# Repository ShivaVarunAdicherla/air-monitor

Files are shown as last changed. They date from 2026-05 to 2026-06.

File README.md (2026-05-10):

# Air Monitor
## Status
- PCB Design - Completed
- Components - Arrived
- Firmware - BLE advertisement tested
- Enclosure - In progress - [Here](https://cad.onshape.com/documents/7cc096864f16c057a6e9d4d9/w/91c0470fa62f2376e8363204/e/8dff4a441c052faf6f8fa123)
- Order Status - Placed and Inprogress/Pre-Engineering

# $\mu$Air
$\mu$Air is a compact air monitoring device, capable of measuring concentrations of multiple essential local atmospheric parameters like: 
- PM2.5 - Particulate Matter
- Nitrogen Oxides ($NO_x$) 
- Carbon Dioxide ($CO_2$)
- Volatile Organic Compounds (VOCs)
- Temperature and Humidity

Each of these is measured using the following:
- BMV080 - Particulate Matter:
  - Compact - 4.4mm x 3.0mm x 4.4mm
  - $1\frac{\mu g}{m^3}$ PM mass concentration resolution
  - Fanless, uses lasers 
- SGP41 - VOCs and $NO_x$ 
- SCD40 - $CO_2$, temperature and humidity

While each of these parameters is measured and can be monitored/inspected individually, an overall quantitative measure of the ambient atmosphere, the AQI (Air Quality Index), is also calculated using these parameters. 

## User Interaction:
AQI, as well as each of the parameters, individually, can be accessed by the user in two ways:
1. 0.96'' OLED Display on device - Push button to wake
2. HomeAssistant App/Server

## Implementation


## Schematic


### Explanation
1. Power
   - Primary Source: 1000mAh Li-Po Battery, or direct power from USB, when connected - Bypass charging handled using a PMOS and a schottky diode, as seen in the schematic.
   - Regulated Power Supply: Buck converter (whose input comes from the output of the bypass charging module - PMOS + Schottky) steps $VIN$ down to $3.3V (V_{DD})$.
   - All other modules, including ESP32-C3 and all the sensors use 3.3V $V_{DD}$ as their power supply.
   - Battery Charging: Handled by DW01 (battery protection IC, inbuilt into the 1000mAh battery), and TC4056, battery charging IC (CC-CV).
2. Sensors
   - BMV080: Measuring PM10, PM2.5 and PM1.0 - Comes in a flex PCB package, with a corresponding female connector placed on the PCB.
   - SCD40: Measuring $CO_2$
   - SGP41: Measuring VOCs and $NO_x$
   - Communication via common I2C bus (except for the BMV080, which has a separate I2C bus) to the ESP32-C3
   - Enclosure designed with suitable openings to allow normal/optimal functioning of all the sensors, as mentioned in their respective application manuals.
3. MCU: ESP32-C3
   - Controls the common I2C bus to receive measurments from the sensors.
   - Handles BLE advertising at regular intervals.
   - Goes into sleep when not broadcasting, saving battery life.
   - Handles the display via the common I2C bus along with a wake button to view parameters on the display.

## PCB Layout




## Firmware Status:
### Framework: ESP-IDF, MicroController: ESP32-C3
For Integration with **Home Assistant** without any other extra configuration for BLE based data broadcast devices, there's an open standard called **BTHome**.
The Second version of the standard has been released quite recently, and the official **BTHOME** component from Espressif doesn't seem to work because it has probably been **depreciated**.

Right now, the code initializes Bluetooth's BLE Stack by Apache Foundation (NimBLE), and starts advertising packets with an interval of 450ms (We've decided on
this rate to save power, while maintaining the balance of packet reception). Right now, since actually don't have the sensor data, we're just generating a random
number/data then building the advertisement packet and sending $\approx 16$ packets in a task loop.

**Note:** We're are building our own implementation of *BTHOME* which sends the sensor data, in the service region of the advertisement packet.

Since ESP-IDF has a native port of FreeRTOS, we plan to take advantage of it's powerful scheduling capabilities to make it easier to organise and build modules
which perform certain tasks. The flowchart will look something like this.



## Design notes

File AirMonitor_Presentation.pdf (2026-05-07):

## Electronic System Design Project Lab

## Air Monitor

Shiva Varun Adicherla EE24BTECH11201 | Anoop K | EE24BTECH11203
Sai Vedhamsh Kema EE24BTECH11211 Shubhang Kulkarni EE24BTECH11222

## 1 Features:

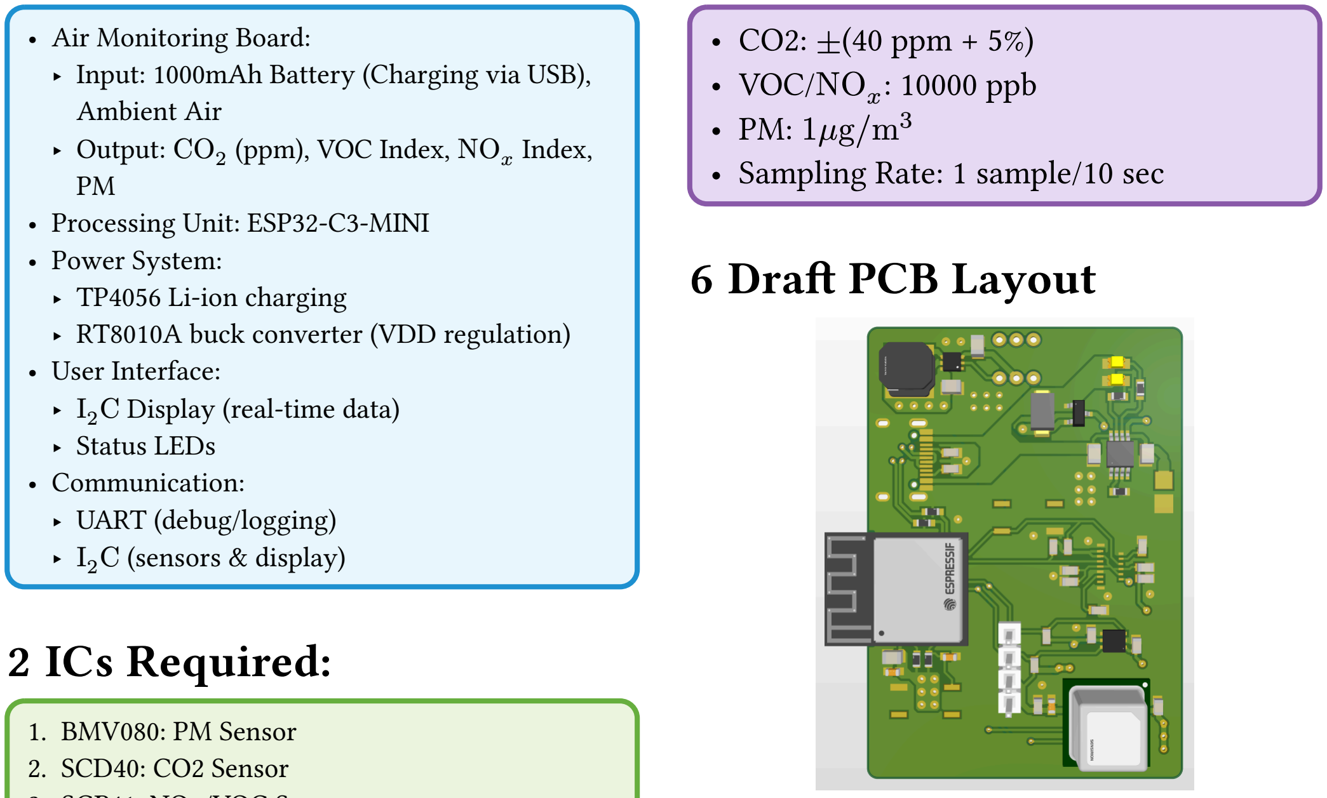
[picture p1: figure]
• Air Monitoring Board:; Ambient Air ‣ Output: CO2; (ppm), VOC Index, NOx; Index,; PM • Processing Unit: ESP32-C3-MINI • Power System: ‣ TP4056 Li-ion charging; • User Interface: ‣ I2C Display (real-time data) ‣ Status LEDs • Communication: ‣ UART (debug/logging) ‣ I2C (sensors & display); 2 ICs Required:; 1. BMV080: PM Sensor 2. SCD40: CO2 Sensor; • CO2: ±(40 ppm + 5%) • VOC/NOx; : 10000 ppb • PM: 1μg/m³; • Sampling Rate: 1 sample/10 sec; 6 Draft PCB Layout

- Input: 1000mAh Battery (Charging via USB),
- RT8010A buck converter (VDD regulation)
3. SGP41: NOx/VOC Sensor
4. TC4056: Battery charger IC
5. ESP32-C3-MINI: MCU
6. RT8010/A: DC-DC Converter

## 3 Cost

### - Components (Active+Passive): 6900 INR

## 4 Block Diagram

## 5 Measurement Specifications

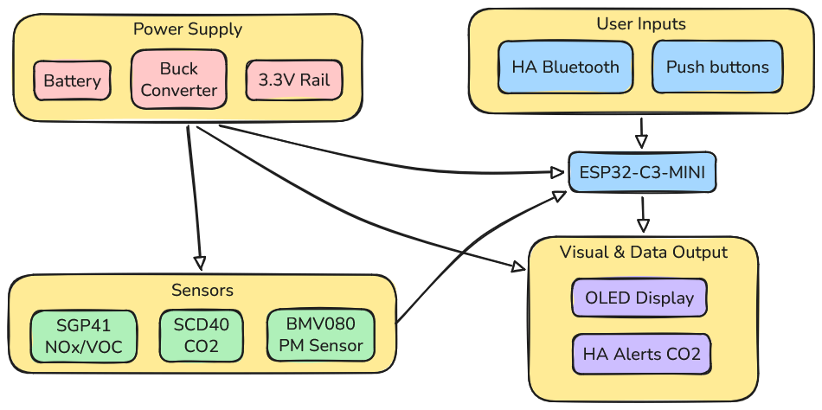
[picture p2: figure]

# EE2504 - Project Idea Local Climate Monitor

19-03-2026

# Our Idea - Smart Air Quality Monitor

# Problem :

# 1. Most indoor workplaces are not monitored for potentially harmful

environments.

# 2. If monitored also, not coupled with IoT for remote access / control

of other IoT devices.

# Our Idea - Smart Air Quality Monitor

# Solution:

## 1. Constantly monitor local environmental

parameters (air quality, CO2 levels,

## temperature, humidity) 2. Make remote access available (along with alerts in certain cases of abnormal changes in parameters) 3. Extension - use this data to control other IoT devices (example: controlling an air purifier fan based on AQI, controlling a fan based on temp/humidity )

# Block diagram

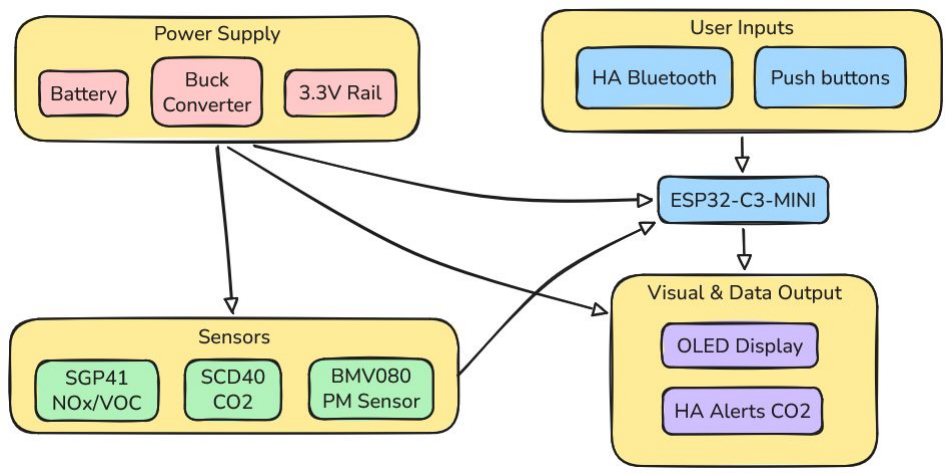
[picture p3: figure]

# Targets

# - Realtime parameters monitoring using input of multiple sensors - IoT integration with Home Assistant

## - Alerts (abnormal change in parameters) - Realtime Info

# Sensors

# - BMV080 sensor for measuring particulate matter - SCD40 for CO2 as well as measuring temperature and humidity - SGP41

- Gas sensor - NOx , VOC etc..

# Components and cost

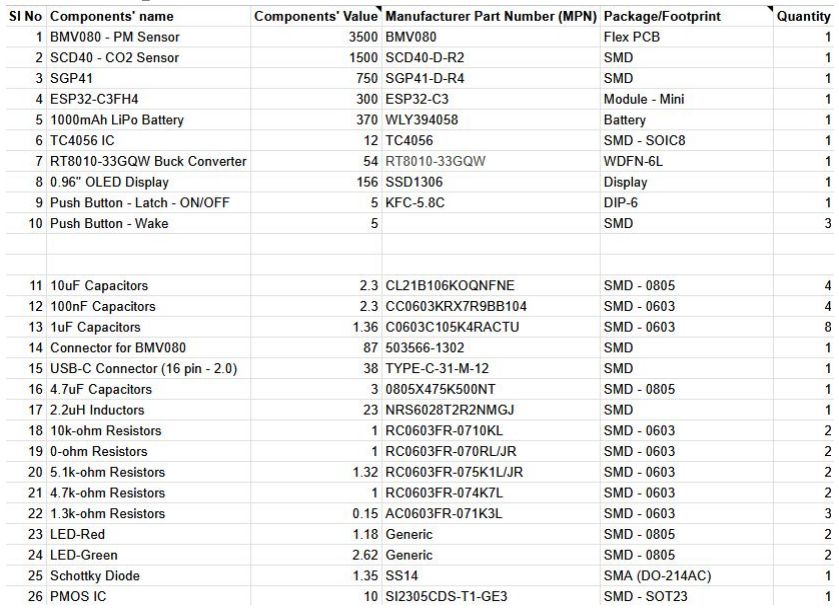
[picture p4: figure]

# Thank you

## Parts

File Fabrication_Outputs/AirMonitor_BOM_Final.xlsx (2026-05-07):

Name | Description | Manufacturer 1 | Manufacturer Part Number 1 | Supplier 1 | Supplier Part Number 1 | DNP | Total Quantity | Designators
C0603C105K4RACTU | 16V 1uF X7R ±10% 0603 Multilayer Ceramic Capacitors MLCC - SMD/SMT ROHS | Yageo Group | C0603C105K4RACTU |  |  |  | 8 | C1, C2, C3, C4, C8, C14, C15, C17
CL21B106KOQNFNE | Multilayer Ceramic Capacitor, 10 uF, 10 V, ± 10%, X7R, 0805 [2012 Metric] | Murata | CL21B106KOQNFNE |  |  |  | 4 | C5, C6, C10, C12
CC0603KRX7R9BB104 | Multilayer Ceramic Capacitor, CC Series, 0.1 - F, - 10%, X7R, 50 V, 0603 [1608 Metric] | Yageo Group | CC0603KRX7R9BB104 |  |  |  | 3 | C7, C9, C11
0805X475K500NT | 0805X475K500NT-FH -50V 4.7uF X5R±10% 0805 Multilayer Ceramic Capacitors MLCC – SMD/SMT ROHS | FH (Guangdong Fenghua Advanced Tech) | 0805X475K500NT |  |  |  | 1 | C13
LEDRED | LED RED CLEAR 0805 SMD | Generic_RED | Generic_RED | Robu.in | 827887 |  | 1 | D1
LEDGREEN | LED GREEN CLEAR 0805 SMD | Generic_GREEN | Generic_GREEN | Robu.in | 827885 |  | 1 | D2
SS14 | SS14-Slkor-40V 550mV@1A 1A SMA(DO-214AC) Schottky Diodes ROHS | Slkor | SS14 | Robu.in | R193202 |  | 1 | D3
5035661302 | Easy-On FPC Connector, 0.30mm Pitch, Right-Angle, Bottom Contact, 0.95mm Height, 13 Circuits, Gold over Nickel Plating | Molex Connector Corporation | 5035661302 | Mouser | 538-503566-1302 |  | 1 | J1
TYPE-C-31-M-12 | TYPE-C-31-M-12-Hroparts-5A 1 16P Female Type-C SMD USB Connectors ROHS | HRO Electronics | TYPE-C-31-M-12 | Robu.in | R243053 |  | 1 | J2
NRS6028T2R2NMGJ | Inductor Power Shielded Wirewound 2.2uH 30% 100KHz Ferrite 3.7A 0.026Ohm DCR 2424 T/R | TAIYO YUDEN | NRS6028T2R2NMGJ | Digikey | 587-2939 |  | 1 | L1
ESP32-C3-MINI-1-H4 | -96dBm 20.5dBm PCBAntenna 2.4GHz SMD, 13.2x16.6mm WiFi Modules ROHS | Espressif Systems | ESP32-C3-MINI-1-H4 | Digikey | 5407-ESP32-C3-MINI-1-H4 |  | 1 | MD1
Berg Pins | 0.025" SQ Post Header, Through-hole, Vertical, -55 to 125 degC, 2.54 mm Pitch, 4-Pin, Male, RoHS |  | DNP |  |  | YES | 1 | P1
AC0603FR-071K3L | RES 1.3KΩ 1.00% 0.1W 0603 | Yageo Group | AC0603FR-071K3L | Robu.in | R137937 |  | 3 | R1, R2, R5
RC0603FR-075K1L | Res Thick Film 0603 5.1K Ohm 1% 0.1W(1/10W) ±100ppm/C Pad SMD T/R | Yageo Group | RC0603FR-075K1L | Robu.in | R135867 |  | 4 | R3, R4, R14, R15
RC0603FR-0710KL | 100mW Thick Film Resistors ±100ppm/℃ ±1% 10kΩ 0603 Chip Resistor - Surface Mount ROHS | Yageo Group | RC0603FR-0710KL | Robu.in | R242876 |  | 2 | R6, R7
GPR06034K7 | SMD Chip Resistor, 4.7 kohm, ± 1%, 100 mW, 0603 [1608 Metric], Thick Film, General Purpose | PCBPower | GPR06034K7 | PCBPower |  |  | 4 | R8, R9, R10, R11
RC0603FR-070RL | Zero Ohm Resistor, Jumper, 0603 [1608 Metric], Thick Film, 100 mW, 1 A, Surface Mount | Yageo Group | RC0603FR-070RL | Robu.in | 1797992 |  | 2 | R12, R13
TK-052 | Tact Switch-TK-052-4 Pin 4×4 | Generic | TK-052 | Robu.in | 1883750 |  | 3 | SW1, SW2, SW3
KFC-5.8C | Self Lock Switch-KFC-KFC-5.8C | Generic | KFC-5.8C | Robu.in | 1883578 |  | 1 | SW4
TC4056 | TC4056-Fumen Electronics Co. Ltd.-1A Standalone Linear Li-Ion Battery Charger IC 8-SOIC | Fuman | TC4056 | Robu.in | R162796 |  | 1 | U1
SCD40-D-R2 | Air Quality Sensor CO2 Sensor 2.5V/3.3V/5V 20-Pin SMD EP T/R | Sensirion | SCD40-D-R2 | Robu.in | R155005 |  | 1 | U2
SI2305CDS-T1-GE3 | P-CHANNEL 8-V (D-S) MOSFET | Vishay | SI2305CDS-T1-GE3 | Robu.in | R231218 |  | 1 | U3
RT8010-33GQW | Switching Regulator, Voltage-mode, 1A, 1800kHz Switching Freq-Max, PDSO6 | Richtek | RT8010-33GQW | DigiKey | 1028-RT8010-33GQW |  | 1 | U4
SGP41-D-R4 | NOx and VOC Sensor with a Secondary Humidity and Temperature Output | Sensirion | SGP41-D-R4 | DigiKey | 1649-SGP41-D-R4 |  | 1 | U5

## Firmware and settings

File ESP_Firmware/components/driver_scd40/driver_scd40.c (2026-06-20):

#include "include/driver_scd40.h"
#include "driver/i2c_types.h"
#include "esp_compiler.h"
#include "esp_err.h"
#include "esp_log.h"
#include "esp_log_buffer.h"
#include "esp_log_level.h"
#include "freertos/idf_additions.h"
#include "freertos/projdefs.h"
#include "hal/i2c_types.h"
#include <driver/i2c_master.h>
#include <stdint.h>

// Logging toggle
#define LOG
#ifdef LOG
#define OLOG(x) ESP_LOGI("SCD40 Driver", x)
#else
#define OLOG(x) x
#endif

// Command List, obtained from pg.no 8 of SCD4X Datasheet. (Big endian)
#define SCD40_START_PERIODIC_MEASUREMENT (uint16_t *)"\x21\xb1"
#define SCD40_START_LOW_POWER_PERIODIC_MEASUREMENT (uint16_t *)"\x21\xac"
#define SCD40_STOP_PERIODIC_MEASUREMENT (uint16_t *)"\x3f\x86"
#define SCD40_GET_DATA_READY_STATUS (uint16_t *)"\xe4\xb8"
#define SCD40_READ_MEASUREMENT (uint16_t *)"\xec\x05"
#define SCD40_REINIT (uint16_t *)"\x36\x46"

esp_err_t scd40_init(i2c_master_bus_handle_t bus_handle, uint32_t speed,
                     scd40 *device) {
  i2c_device_config_t config = {.device_address = 0x62,
                                .dev_addr_length = I2C_ADDR_BIT_LEN_7,
                                .scl_speed_hz = speed,
                                .flags.disable_ack_check = false,
                                .scl_wait_us = 5000};

  return i2c_master_bus_add_device(bus_handle, &config, &device->dev_handle);
}

uint8_t scd40_crc(const uint8_t *data, uint8_t count) {
  // We init CRC checks with 0xFF (Pg: 23 of SCD4X Datasheet)
  uint8_t crc = 0xFF;
  const uint8_t CRC_POLY = 0x31;

  for (uint8_t current_byte = 0; current_byte < count; current_byte++) {
    crc ^= data[current_byte];
    for (uint8_t bit = 8; bit > 0; bit--) {
      if (crc & 0x80) // Check MSB
        crc = (crc << 1) ^ CRC_POLY;
      else
        crc = (crc << 1);
    }
  }
  return crc;
}

esp_err_t scd40_send_command(const uint16_t *command, scd40 *device) {
  return i2c_master_transmit(device->dev_handle, (uint8_t *)command, 2, 15);
}

esp_err_t scd40_read(const uint16_t *command, scd40 *device, uint8_t *buffer,
                     uint8_t length, uint8_t delay_in_ms) {
  esp_err_t error =
      i2c_master_transmit(device->dev_handle, (uint8_t *)command, 2, 15);
  if (unlikely(error != ESP_OK)) {
    OLOG("Failed a I2C Transmit");
    return error;
  }

  vTaskDelay(pdMS_TO_TICKS(delay_in_ms));

  error = i2c_master_receive(device->dev_handle, buffer, length, 15);
  if (unlikely(error != ESP_OK)) {
    OLOG("Failed a I2C Receive");
    return error;
  }
  esp_log_buffer_hex_internal("SCD40 Driver", buffer, length, ESP_LOG_INFO);

  return error;
}

esp_err_t scd40_start_periodic_measurement(scd40 *device) {
  OLOG("Starting Periodic Measurement");
  return scd40_send_command(SCD40_START_PERIODIC_MEASUREMENT, device);
}

esp_err_t scd40_start_low_power_periodic_measurement(scd40 *device) {
  OLOG("Starting Low Power Periodic Measurement");
  return scd40_send_command(SCD40_START_LOW_POWER_PERIODIC_MEASUREMENT, device);
}

esp_err_t scd40_stop_periodic_measurement(scd40 *device) {
  OLOG("Stopping Periodic Measurement");
  return scd40_send_command(SCD40_STOP_PERIODIC_MEASUREMENT, device);
}

esp_err_t scd40_read_measurement(scd40 *device, int *temp_c_deg,
                                 int *humidity_rh_percent, uint16_t *co2_ppm) {

  // TODO: Add Define Options to enable checking CRC. (We aren't checking now)

  uint8_t buf[9];
  esp_err_t error = scd40_read(SCD40_READ_MEASUREMENT, device, buf, 9, 2);
  if (unlikely(error != ESP_OK)) {
    OLOG("Failed Reading Measurement");
    *temp_c_deg = 0;
    *humidity_rh_percent = 0;
    *co2_ppm = 0;
    return error;
  }

  // Tick Conversion - SCD4X Datasheet pg.no 9
  *temp_c_deg = ((((int)buf[3] << 8) | buf[4]) * 175) / ((1 << 16) - 1) - 45;
  *humidity_rh_percent =
      ((((int)buf[6] << 8) | buf[7]) * 100) / ((1 << 16) - 1);
  *co2_ppm = ((uint16_t)buf[0] << 8) | buf[1];
  OLOG("Read measurements");
  return error;
}

uint8_t scd40_get_data_ready_status(scd40 *device) {
  uint8_t buf[3];
  scd40_read(SCD40_GET_DATA_READY_STATUS, device, buf, 3, 2);
  // OLOG("Polled for data ready flag");
  return (((uint16_t)buf[0] << 8) | buf[1]) &
         0x7FFF; // SCD4X Datasheet pg.no 16
}

esp_err_t scd40_reinit(scd40 *device) {
  OLOG("Restarting SCD40");
  return scd40_send_command(SCD40_REINIT, device);
}

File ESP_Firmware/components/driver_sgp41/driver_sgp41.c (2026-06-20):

#include "driver_sgp41.h"
#include "driver/i2c_master.h"
#include "driver/i2c_types.h"
#include "esp_err.h"
#include "esp_log.h"
#include "esp_log_buffer.h"
#include "esp_log_level.h"
#include "freertos/idf_additions.h"
#include "freertos/projdefs.h"
#include "hal/i2c_types.h"
#include <esp_compiler.h>
#include <stdint.h>

// Logging toggle
#define LOG
#ifdef LOG
#define OLOG(x) ESP_LOGI("SGP41 Driver", x)
#define OLOGF(x, y) ESP_LOGI("SGP41 Driver", x, y)
#define OLOGF2(x, y, z) ESP_LOGI("SGP41 Driver", x, y, z)
#else
#define OLOG(x) x
#define OLOGF(x, y) x
#define OLOGF2(x, y, z) x
#endif

esp_err_t sgp41_init(i2c_master_bus_handle_t bus_handle, uint32_t speed,
                     sgp41 *device) {
  i2c_device_config_t config = {
      .device_address = 0x59,
      .dev_addr_length = I2C_ADDR_BIT_LEN_7,
      .scl_speed_hz = speed,
      .scl_wait_us = 20000,
      .flags.disable_ack_check = true,
  };

  OLOG("SGP41 Sensor Init");
  return i2c_master_bus_add_device(bus_handle, &config, &device->dev_handle);
}

uint8_t sgp41_crc(const uint8_t *data, uint8_t count) {
  // We init CRC checks with 0xFF (Pg: 13 of SGP41 Datasheet)
  uint8_t crc = 0xFF;
  const uint8_t CRC_POLY = 0x31;

  for (uint8_t current_byte = 0; current_byte < count; current_byte++) {
    crc ^= data[current_byte];
    for (uint8_t bit = 8; bit > 0; bit--) {
      if (crc & 0x80) // Check MSB
        crc = (crc << 1) ^ CRC_POLY;
      else
        crc = (crc << 1);
    }
  }
  return crc;
}
esp_err_t sgp41_execute_conditioning(sgp41 *device, uint16_t default_rh_percent,
                                     uint16_t default_temp_c_deg) {
  uint8_t buf[8] = {0x26, 0x12};
  unsigned int rh = (unsigned int)default_rh_percent * 65535U;
  unsigned int temp = (default_temp_c_deg + 45) * 65535U;
  rh /= 100;
  temp /= 175;
  default_rh_percent = rh;
  default_temp_c_deg = temp;

  buf[2] = default_rh_percent >> 8;
  buf[3] = default_rh_percent;
  buf[4] = sgp41_crc(buf + 2, 2);
  buf[5] = default_temp_c_deg >> 8;
  buf[6] = default_temp_c_deg;
  buf[7] = sgp41_crc(buf + 5, 2);

  uint8_t rec_buf[3];
  // esp_log_buffer_hex_internal("SGP41 Execute Conditioning", buf, 8,
  // ESP_LOG_INFO);
  esp_err_t error = i2c_master_transmit(device->dev_handle, buf, 8, -1);
  if (unlikely(error != ESP_OK)) {
    OLOG("Execute Conditioning Failed at I2C Transmit");
    return error;
  }

  vTaskDelay(pdMS_TO_TICKS(50));

  error = i2c_master_receive(device->dev_handle, rec_buf, 3, -1);
  if (unlikely(error != ESP_OK)) {
    OLOG("Execute Conditioning Failed at I2C Receive");
    return error;
  }

  // esp_log_buffer_hex_internal("SGP41 Conditioning RAW", rec_buf, 3,
  //                             ESP_LOG_INFO);
  OLOGF("Execute Conditioning: VOC- %hu", *(uint16_t *)rec_buf);
  return error;
}

esp_err_t sgp41_read_raw_measurements(sgp41 *device, uint16_t rh_percent,
                                      uint16_t temp_c_deg, uint16_t *raw_NOX,
                                      uint16_t *raw_VOC) {
  uint32_t rh = rh_percent * 65535;
  uint32_t temp = (temp_c_deg + 45) * 65535;
  rh /= 100;
  temp /= 175;
  rh_percent = rh;
  temp_c_deg = temp;

  uint8_t buf[8] = {
      0x26,       0x19, rh_percent >> 8, rh_percent, 0x00, temp_c_deg >> 8,
      temp_c_deg, 0x00,
  };
  buf[4] = sgp41_crc(buf + 2, 2);
  buf[7] = sgp41_crc(buf + 5, 2);

  esp_err_t error = i2c_master_transmit(device->dev_handle, buf, 8, -1);
  if (unlikely(error != ESP_OK)) {
    OLOG("Execute Conditioning Failed at I2C Transmit");
    *raw_VOC = 0xFFFF;
    *raw_NOX = 0xFFFF;
    return error;
  }

  // esp_log_buffer_hex_internal("SGP41 READ RAW", buf, 8, ESP_LOG_INFO);

  vTaskDelay(pdMS_TO_TICKS(60));

  uint8_t rec_buf[6];
  error = i2c_master_receive(device->dev_handle, rec_buf, 6, -1);
  if (unlikely(error != ESP_OK)) {
    OLOG("Execute Conditioning Failed at I2C Receive");
    *raw_VOC = 0xFFFF;
    *raw_NOX = 0xFFFF;
    return error;
  }

  // esp_log_buffer_hex_internal("SGP41 RAW DATA", rec_buf, 6, ESP_LOG_INFO);

  // TODO: Add CRC checking
  *raw_VOC = ((uint16_t)rec_buf[0] << 8) | rec_buf[1];
  *raw_NOX = ((uint16_t)rec_buf[3] << 8) | rec_buf[4];

  OLOGF2("Read RAW Measurements: VOC- %hu NOX- %hu", *raw_VOC, *raw_NOX);
  return error;
}

// Rarely used func imo, so ESP_ERROR_CHECK is used while returning a uint8_t
// flag
uint8_t sgp41_execute_self_test(sgp41 *device) {
  ESP_ERROR_CHECK(
      i2c_master_transmit(device->dev_handle, (uint8_t *)"\x28\x0E", 2, -1));

  vTaskDelay(pdMS_TO_TICKS(321));

  uint8_t rec_buf[3];
  ESP_ERROR_CHECK(i2c_master_receive(device->dev_handle, rec_buf, 3, -1));
  esp_log_buffer_hex_internal("SGP41 Self Test", rec_buf, 3, ESP_LOG_INFO);

  if (rec_buf[1] & 0x03) {
    OLOGF("Self Test Failed: Received %x", rec_buf[1] & 0x03);
    return 0; // Return 0 if tests failed
  }
  OLOGF("Self Test Passed: Received %x", rec_buf[1] & 0x03);
  return 1;
}

esp_err_t sgp41_turn_heater_off(sgp41 *device) {

  esp_err_t error =
      i2c_master_transmit(device->dev_handle, (uint8_t *)"\x36\x15", 2, -1);
  if (unlikely(error != ESP_OK)) {
    OLOG("Execute Conditioning Failed at I2C Transmit");
    return error;
  }
  OLOG("Turned Off Heater");
  return error;
}

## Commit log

2026-02-25 Managed project "Air_Monitor_ESDP" created from AD
    [Air_Monitor_ESDP.PrjPcb]
2026-02-26 Added AP2112
    [Sheet1.SchDoc]
2026-02-26 added display module (7-pin connector)
    [Sheet1.SchDoc]
2026-02-26 added BMV080 as a connector
    [Air_Monitor_ESDP.PrjPcb, Sheet1.SchDoc]
2026-02-26 added bmv080
    [Air_Monitor_ESDP.PrjPcb, Sheet1.SchDoc]
2026-02-26 added symbol for RT8010 and added its schematic
    [Sheet1.SchDoc]
2026-02-27 added some parts of c3-mini (power, EN, USB)
    [Sheet1.SchDoc]
2026-02-27 added usb connector symbol
    [Sheet1.SchDoc]
2026-02-28 updated esp32c3 with sda/scl and boot (both on same set of pins)
    [Sheet1.SchDoc]
2026-02-28 removed ap2112
    [Sheet1.SchDoc]
2026-02-28 Added Battery Charger
    [Sheet1.SchDoc]
2026-03-01 added DW01
    [Sheet1.SchDoc]
2026-03-01 added dw01 for battery protection (similar to the TP4056 module)
    [Sheet1.SchDoc]
2026-03-01 added bypass charging using a schottky diode and a pmos
    [Sheet1.SchDoc]
2026-03-01 Complete migration of BMV to new I2C Line
    [Sheet1.SchDoc]
2026-03-03 Fixed all the footprint and symbol issues
    [Sheet1.SchDoc]
2026-03-03 Completed ERC verification, and added Net Names to all the nets
    [Air_Monitor_ESDP.PrjPcb, PCB1.PcbDoc, Sheet1.SchDoc]
2026-03-12 placement pcb after removing cap for sw2
    [PCB1.PcbDoc]
2026-03-12 Added a switch.
    [Sheet1.SchDoc]
2026-03-12 Switch annotation
    [Sheet1.SchDoc]
2026-03-12 Resolve the Enable Issue
    [Sheet1.SchDoc]
2026-03-13 Basic Placement and routing (Clumped)
    [PCB1.PcbDoc, Sheet1.SchDoc]
2026-03-18 Change the I2C pin assignments.
    [Sheet1.SchDoc]
2026-03-18 Schematic Pin Changes
    [Sheet1.SchDoc]
2026-03-18 PCB and Schematic Stuff
    [PCB1.PcbDoc, Sheet1.SchDoc]
2026-03-19 Minor pin Changes and Routing of all non-power nets.
    [PCB1.PcbDoc, Sheet1.SchDoc]
2026-03-19 Some Power polygons routed.
    [PCB1.PcbDoc, Sheet1.SchDoc]
2026-03-19 Power Polygon pours
    [PCB1.PcbDoc]
2026-03-19 Finish Routing
    [Air_Monitor_ESDP.PrjPcb, PCB1.PcbDoc]
2026-03-21 Some improvements
    [Air_Monitor_ESDP.PrjPcb, PCB1.PcbDoc]
2026-03-26 Make designators big again
    [PCB1.PcbDoc]
2026-03-26 added wake switch and updated footprint
    [Air_Monitor_ESDP.PrjPcb, PCB1.PcbDoc, Sheet1.SchDoc]
2026-04-02 final changes - board outline, mounting holes
    [Air_Monitor_ESDP.PrjPcb, PCB1.PcbDoc]
2026-04-02 final changes
    [Air_Monitor_ESDP.PrjPcb]
2026-04-09 holes near type-c and pads in bottom layer for solar (if needed)
    [PCB1.PcbDoc]
2026-04-09 stackup updated from PCBpower
    [Air_Monitor_ESDP.PrjPcb, PCB1.PcbDoc]
2026-04-16 final PCB with logo
    [Air_Monitor_ESDP.PrjPcb, PCB1.PcbDoc]
2026-04-28 Reorganise stuff
    [Air_Monitor_ESDP.PrjPcb, PCB1.PcbDoc, Sheet1.SchDoc]
2026-05-07 Added BOM and proposal presentation
    [AirMonitor_BOM_Final.xlsx]
2026-05-08 Update README.md
    added features and implementation flow diagram
2026-05-08 added fabrication outputs
    [AirMonitor_BOM_Final.xlsx, AirMonitor_PnP_Final.xlsx]
2026-05-10 Update README.md
    added description for the implementation and schematic
2026-06-03 Barebones SCD40/SCD4X Driver
2026-06-08 Moved every driver to seperate component
2026-06-12 BMV080 Driver
2026-06-20 Updated and corrected I2C Drivers for Sensiron Sensors
    [driver_scd40.c, driver_sgp41.c]
